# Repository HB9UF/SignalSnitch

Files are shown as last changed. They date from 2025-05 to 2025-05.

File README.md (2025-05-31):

# HB9UF SignalSnitch

## Introduction

At the [Fantasy Basel](https://fantasybasel.ch) 2025, we were thrilled to participate with a booth, sharing the space with [AMSAT-HB](//www.amsat-hb.org/) in the section of the [Swiss Space Museum](https://swissspacemuseum.ch/). As part of our contribution to this unique blend of science, pop culture, and hands-on experiences, we introduced the SignalSnitch -- a simple, educational RF detector kit designed by Andreas HB9HDF.

The SignalSnitch kit was created specifically for this event to spark interest in amateur radio through a hands-on activity that anyone could enjoy. The kit uses through-hole technology (THT) components to keep assembly straightforward and beginner-friendly, making it ideal for both newcomers and seasoned enthusiasts. Once put together, it lights up an LED when it detects the presence of a nearby RF signal, offering a tangible and satisfying introduction to radio frequency detection.

The concept behind SignalSnitch is not entirely new -- it builds upon a [similar kit with SMD parts](https://github.com/HB9UF/aufdermauer/) conceived by Hansjörg HB9DWS and implemented by Matt HB9FRV for the 2019 HAMFEST in Zug.

The response was overwhelmingly positive! We had a fantastic time meeting fellow hobbyists, curious newcomers, and future radio amateurs. We were out of kits long before the fare ended. A heartfelt thank you to everyone who helped make this project possible and to all who stopped by to build their own SignalSnitch. Your enthusiasm made this experience truly memorable.

## Schematic and Theory of Operation
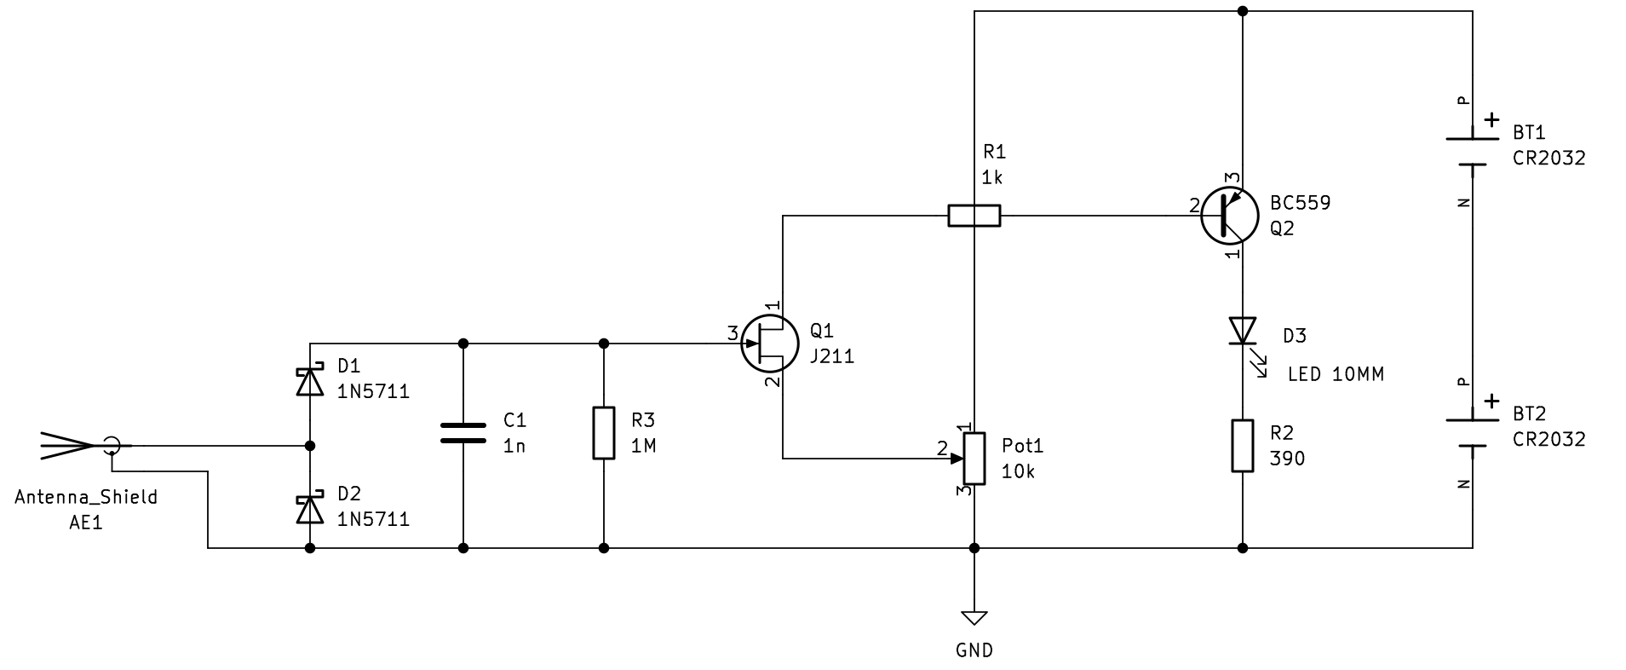
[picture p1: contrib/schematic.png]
Schematic


This simple circuit works as follows: The PCB antenna picks up electromagnetic fields, in consequence, AC voltage develops across the antenna terminals. Diodes `D1` and `D2` rectify this AC voltage to a DC voltage across capacitor `C1`. This DC voltage activates JFET `Q1` which in turn enables `Q2`. Light is emitted by LED `D3` due to the resulting collector current. Bias can be adjusted with `Pot1`.

## PCB
The PCB features the schematic on the front side and a QR code for [assembly instructions](https://hb9uf.ch/snitch). Components are clearly labeled and assembly is straight forward. See below for images of the board as well as a video of the kit in operation.

Top Side Render
Bottom Side Render

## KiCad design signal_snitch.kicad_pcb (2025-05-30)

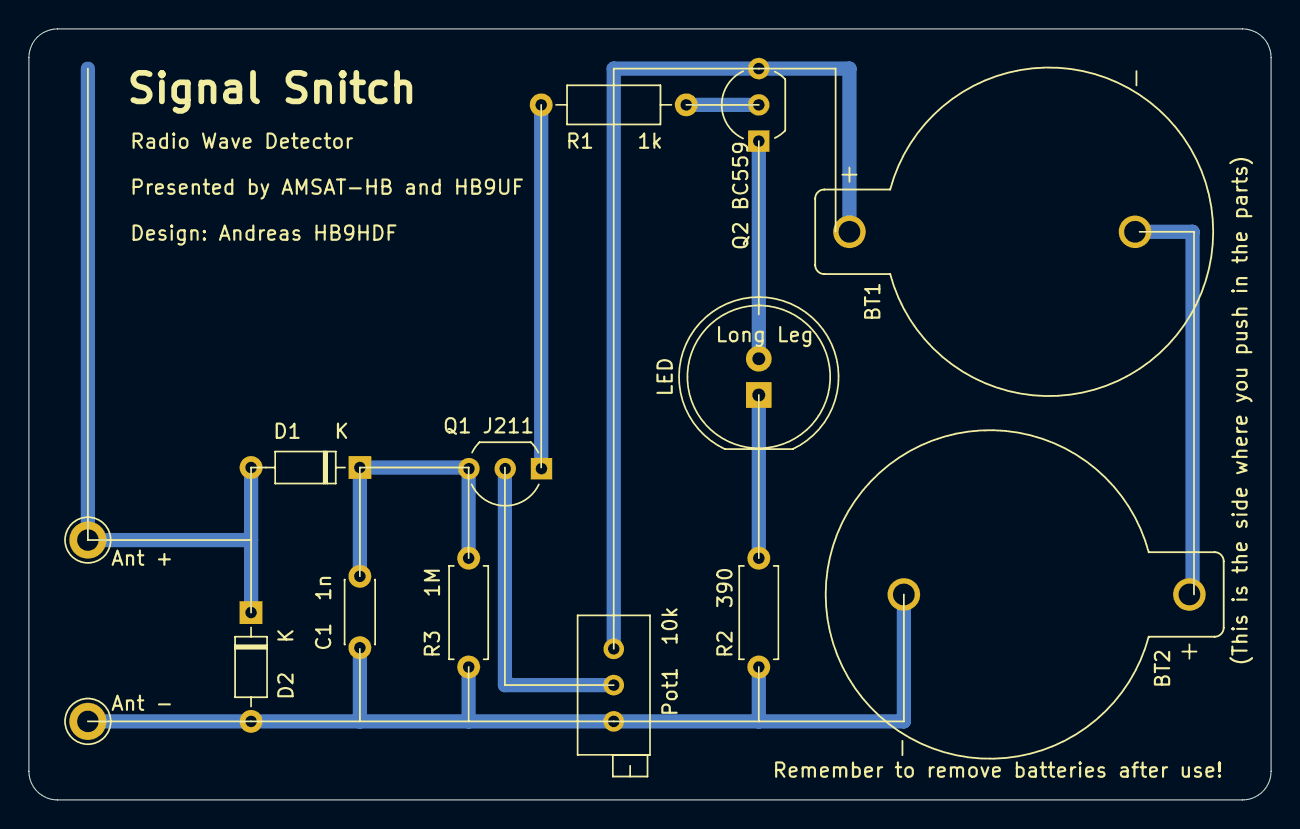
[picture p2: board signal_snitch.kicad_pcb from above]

Board: 2 copper layers, 87.0 x 54.0 mm, 14 parts (0 on the bottom side), 8 nets.

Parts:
Ant +: Pin_D1.3mm_L11.0mm
Ant -: Pin_D1.3mm_L11.0mm
BT1, BT2: CR2032; BAT_1066
C1  1n: 1n; C_Disc_D4.3mm_W1.9mm_P5.00mm
D1, D2: 1N5711; D_DO-35_SOD27_P7.62mm_Horizontal
LED: LED 10MM; LED_D10.0mm
Pot1  10k: 10k; Potentiometer_Bourns_3296X_Horizontal
Q1 J211: TO-92_Inline_Wide
Q2 BC559: BC559; TO-92_Inline_Wide
R1    1k: 1k; R_Axial_DIN0207_L6.3mm_D2.5mm_P10.16mm_Horizontal
R2  390: 390; R_Axial_DIN0207_L6.3mm_D2.5mm_P7.62mm_Horizontal
R3   1M: 1M; R_Axial_DIN0207_L6.3mm_D2.5mm_P7.62mm_Horizontal

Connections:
GND: BT2.N, C1 1n.2, D2.2 (A), Pot1 10k.3, R2 390.1, R3 1M.2
unnamed: D1.2 (A), D2.1 (K)
unnamed: BT1.N, BT2.P
unnamed: C1 1n.1, D1.1 (K), R3 1M.1
unnamed: LED.2 (A), Q2 BC559.1 (C)
unnamed: LED.1 (K), R2 390.2
unnamed: Q2 BC559.2 (B), R1 1k.2
unnamed: BT1.P, Pot1 10k.1, Q2 BC559.3 (E)

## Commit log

2025-05-30 Initial version of KiCad project as designed by HB9HDF
    [signal_snitch.kicad_pcb, signal_snitch.kicad_sch]
2025-05-30 Offset R1 designator in schematic to avoid overlaps
    [signal_snitch.kicad_sch]
2025-05-30 PNG for schematic (to be included in README)
